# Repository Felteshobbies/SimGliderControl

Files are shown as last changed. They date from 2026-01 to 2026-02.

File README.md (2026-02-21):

# SimGliderControl
**Realistic Precision Controller for Glider Flight Simulators**

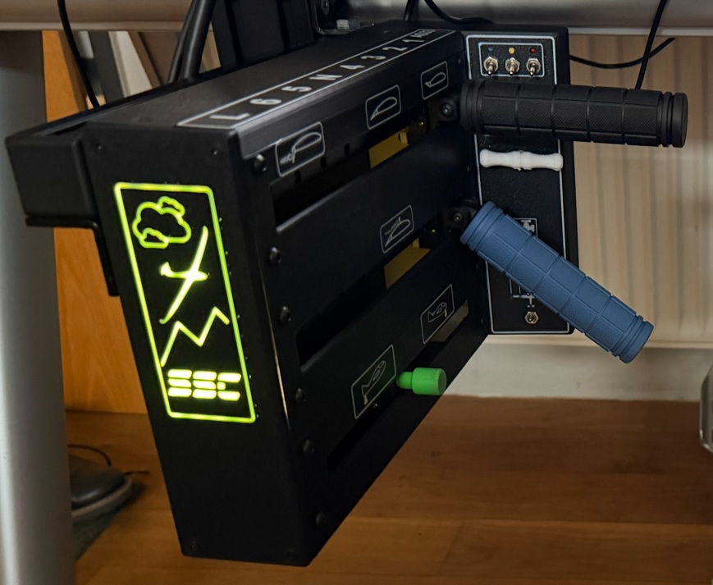
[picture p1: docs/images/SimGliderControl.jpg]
SimGliderControl


## Features
- **Flaps Control** - Smooth, precise flap adjustment
- **Spoiler Control** - Accurate spoiler/airbrake positioning  
- **Trim Control** - Fine trim adjustment with rotary knob
- **Optional Controls** - Tow release, water ballast, wheel brake, electrical systems

## Technical Specifications
- **Arduino UNO** with Mobiflight software integration (or any other controller who support analog in)
- **Ball-bearing linear guides** for smooth, realistic movement
- **Wear-free Hall effect sensors** for precise, long-lasting position detection
- **Modular design** - customize to your cockpit needs

## ⚠️ Disclaimer

This project is provided as-is for educational and hobbyist purposes. While every effort has been made to ensure accuracy, the documentation, designs, and instructions may contain errors or omissions.

**Important Notice:**
- Building and using this controller is **at your own risk**
- The author(s) assume **no liability** for any damages, injuries, or losses resulting from construction or use
- Verify all measurements, specifications, and safety considerations before proceeding
- Electronic components should be handled with appropriate safety precautions
- If you're unsure about any step, seek advice from experienced makers or professionals

By using these plans and instructions, you acknowledge and accept these terms.

## Building Your SimGliderControl

### 3D Printing Instructions
Follow these step-by-step printing guides to create all necessary components:

1. **[Step 1: Base Components](Step1/print-instructions-step1.md)** - Foundation parts including guide shafts, linear guides, and mounting brackets
2. **[Step 2: Carriage Components](Step2/print-instructions-step2.md)** - Moving parts including guides, handle mounts, and detent holders
3. **[Step 3: Enclosure and Panel](Step3/print-instructions-step3.md)** - Housing and control panel options
4. **[Step 4: Control Panel](Step4/print-instructions-step4.md)** - Main cockpit interface panels with optional decals and LED lighting
5. **[Step 5: Handles and Controls](Step5/print-instructions-step5.md)** - Ergonomic handles, trim knob, and release mechanisms

### What You'll Need
- 3D Printer (min. 250×200×200mm build volume recommended)
- PLA and PETG filament
- 1x Arduino UNO or another controller of your choice with analog in
- 3x Hall effect sensors AS5600 Encoder (23mm x 23mm) with magnet (4mm x 2mm)
- 3x MGN12 250mm linear rail with MGN12B carriage
  **Important:** Design optimized for MGN12B (short carriage) for maximum control travel
  - MGN12C compatible: mounting holes identical, but reduces available throw by ~8mm per axis
- 15x bearings 8x3x3mm
- Standard hardware (3mm and 4mm screws and nuts)
- Basic soldering equipment

## Assembly

1. **[Step 1: Base Components](docs/ASSEMBLING-STEP1.md)**
2. **[Step 2: Carriage Assembly](docs/ASSEMBLING-STEP2.md)**
3. **[Step 3: Wiring and Calibration](docs/ASSEMBLING-STEP3.md)**
4. **[Step 4: Case](docs/ASSEMBLING-STEP4.md)**
5. **[Step 5: Handles and Mounting](docs/ASSEMBLING-STEP5.md)**

## Software Setup
*Mobiflight configuration guide coming soon*

## Community
- [Sim Soaring Club Discord](https://discord.com/servers/sim-soaring-club-876123356385149009)
- [Sim Soaring Club](https://simsoaring.club/)
- [B21 Task Planner](https://xp-soaring.github.io/tasks/b21_task_planner/index.html)  
- [WeSimGlide](https://wesimglide.org/)
- [SSC-Tracker ](https://ssc-tracker.org/)

## License
Attribution-NonCommercial-ShareAlike 4.0 International

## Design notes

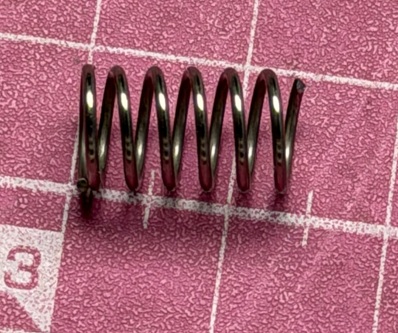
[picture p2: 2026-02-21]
docs/images/s2-6.jpg

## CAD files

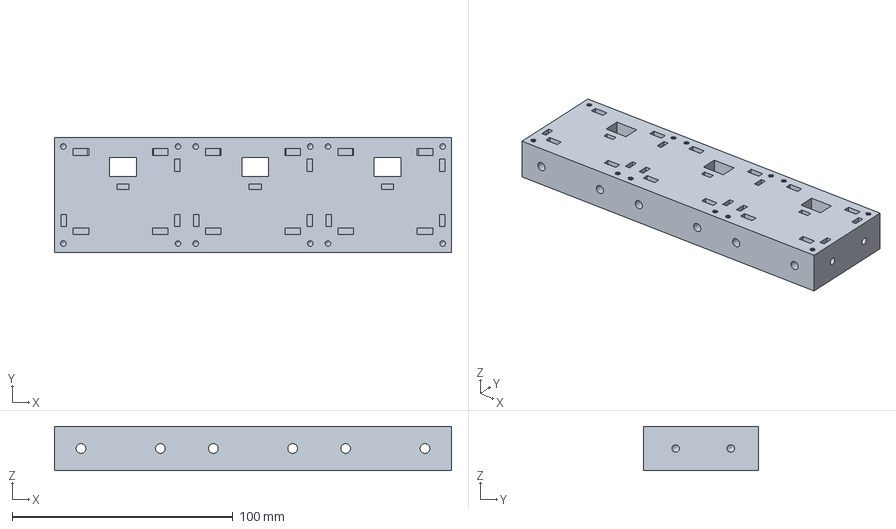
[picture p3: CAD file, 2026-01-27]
Step1/GliderCtrBase_v1-Mount2Assembly.3mf
180.0 x 52.0 x 20.0 mm

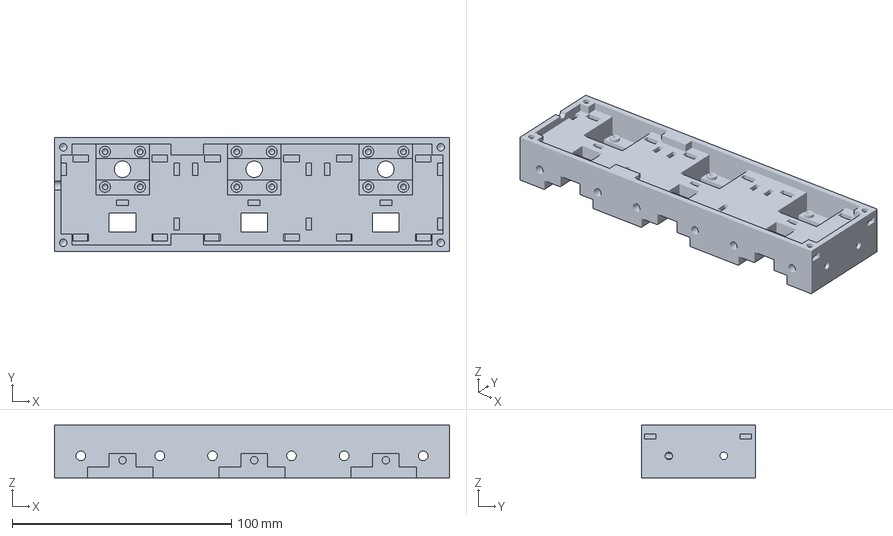
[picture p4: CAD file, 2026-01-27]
Step1/GliderCtrBase_v1-Mount1Assembly.3mf
180.0 x 52.0 x 24.0 mm

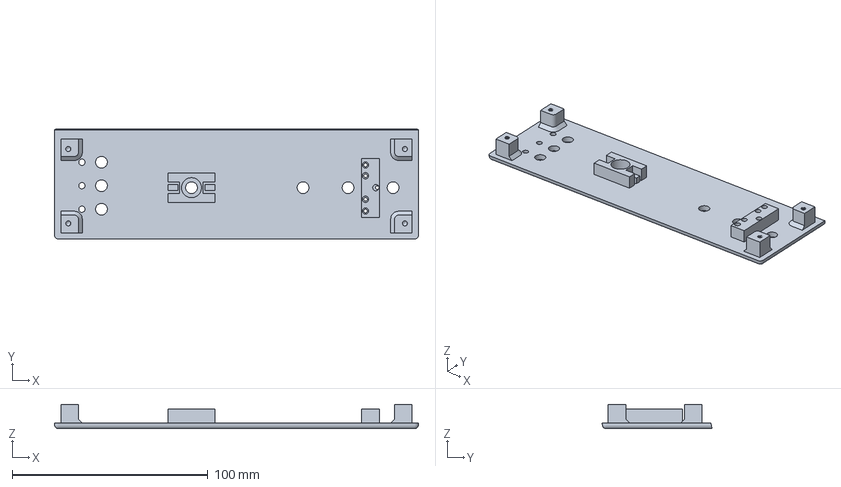
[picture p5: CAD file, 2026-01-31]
Step3/GliderCtrEnclosureAux_v1-PanelFull.3mf
186.0 x 56.2 x 12.5 mm

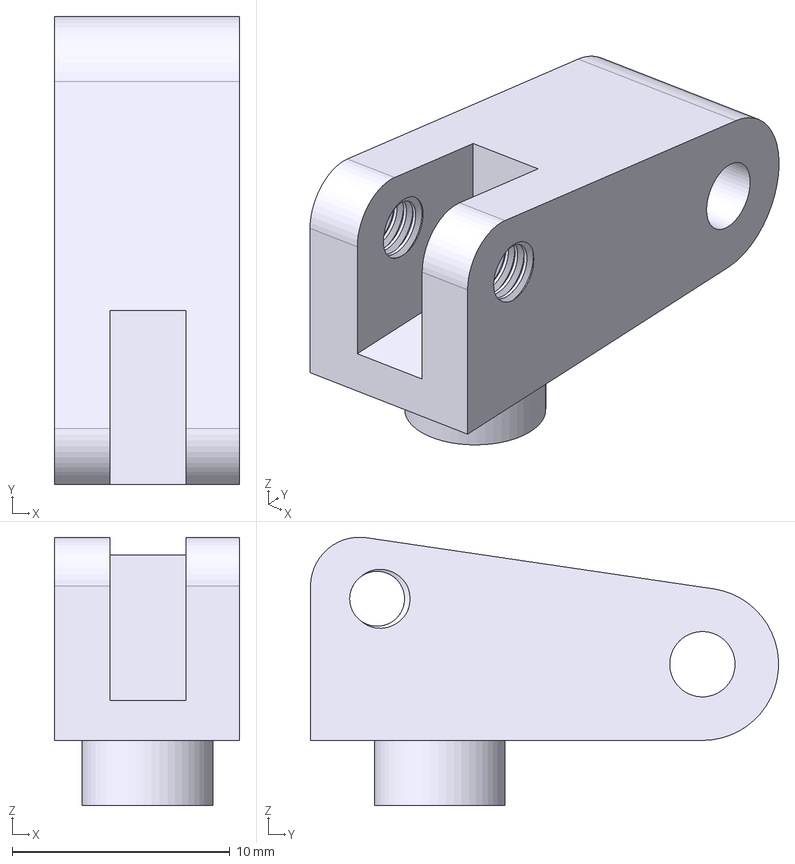
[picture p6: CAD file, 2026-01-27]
Step2/GliderCtrCarriage_v1-DetendHolder.step
8.50 x 21.5 x 12.3 mm

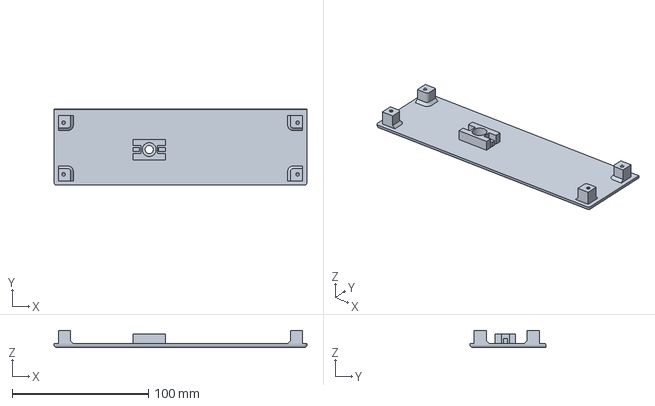
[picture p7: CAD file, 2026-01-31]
Step3/GliderCtrEnclosureAux_v1-PanelSimple.3mf
186.0 x 56.2 x 12.5 mm

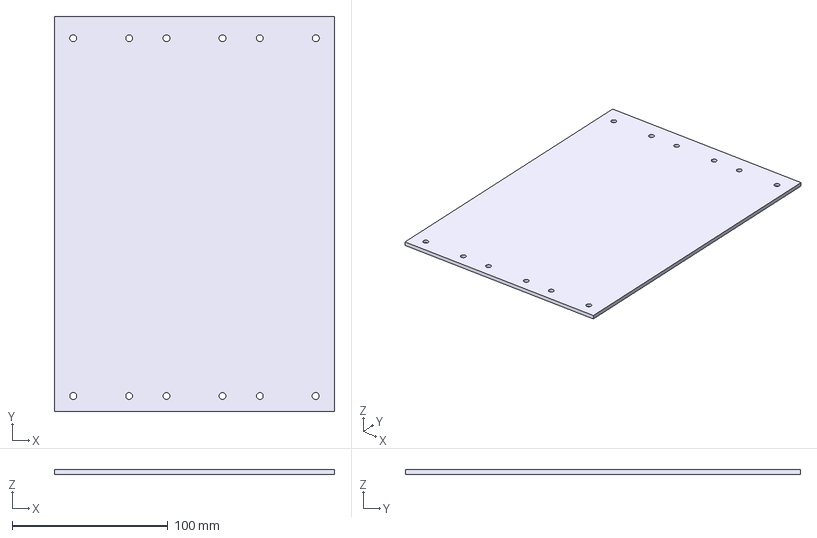
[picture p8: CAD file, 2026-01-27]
Step4/GliderCtrPanel_v1-Back.step
180.0 x 254.0 x 3.00 mm

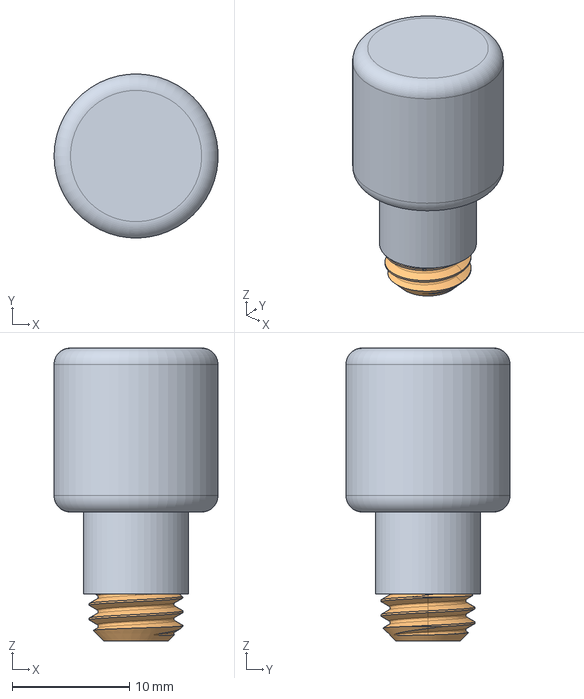
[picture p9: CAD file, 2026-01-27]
Step5/GliderCtrlHandles_v1-TrimKnob.step
14.0 x 14.0 x 25.0 mm
Knob
M8x5-ThreadedRod

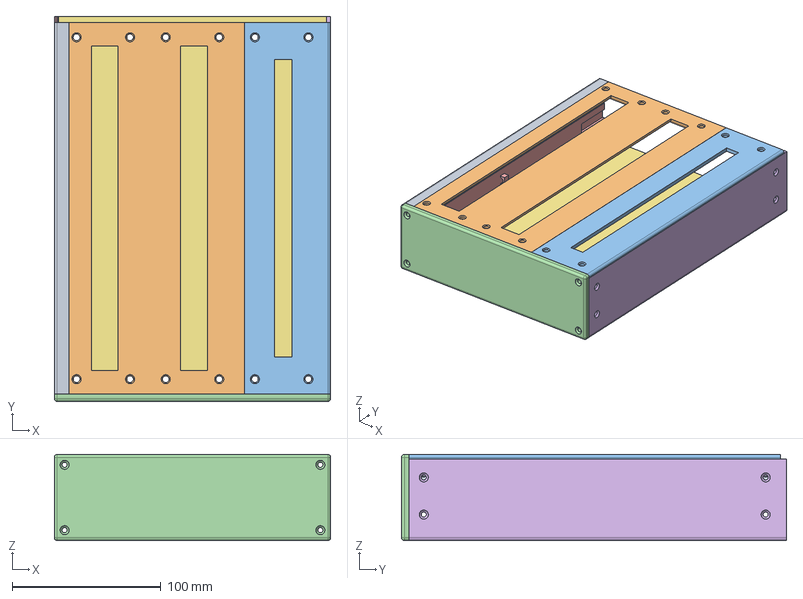
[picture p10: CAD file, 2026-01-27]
CAD/GliderCtrPanel_v1.FCStd
186.0 x 259.0 x 58.0 mm
ScaleAS33
FlapsSpoiler
Trim
front
Top
Bottom
Back

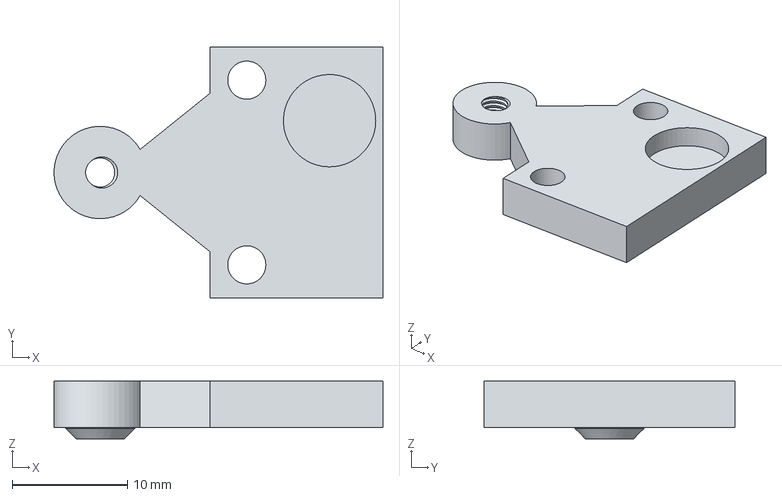
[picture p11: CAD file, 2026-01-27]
Step2/GliderCtrCarriage_v1-FixedGuide.step
28.5 x 21.7 x 5.00 mm

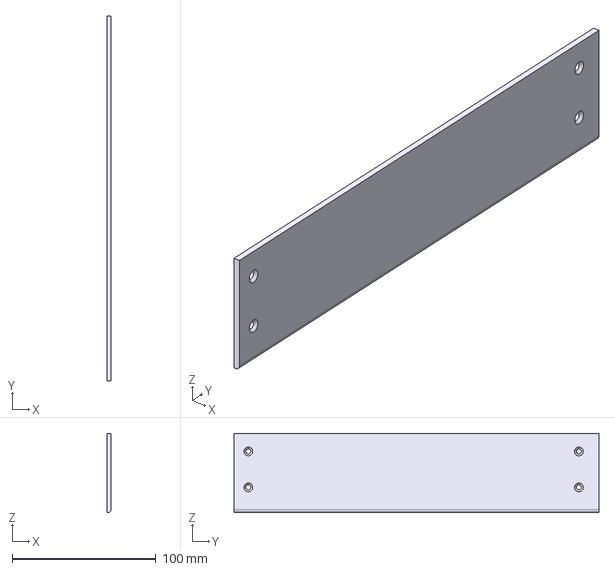
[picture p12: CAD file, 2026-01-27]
Step4/GliderCtrPanel_v1-Bottom.step
3.00 x 254.0 x 55.0 mm

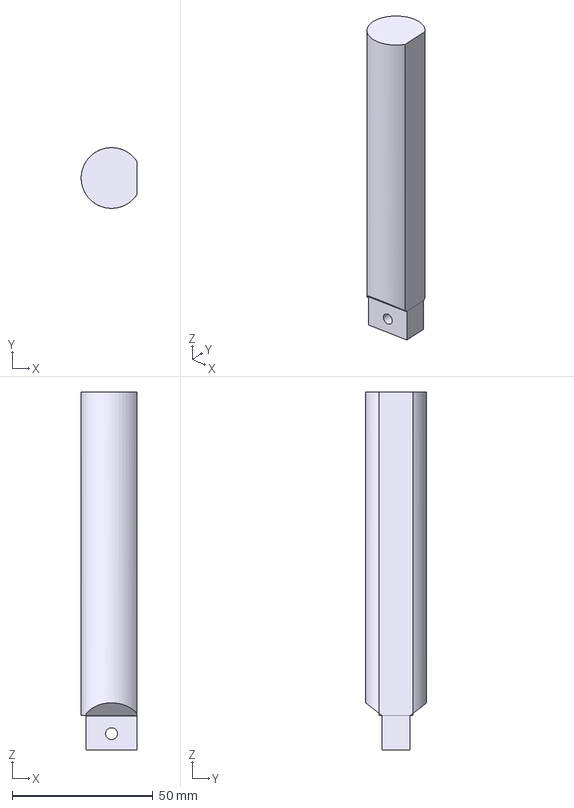
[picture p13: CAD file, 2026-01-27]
Step5/GliderCtrlHandles_v1-TrimFlap90.step
19.8 x 21.6 x 127.3 mm

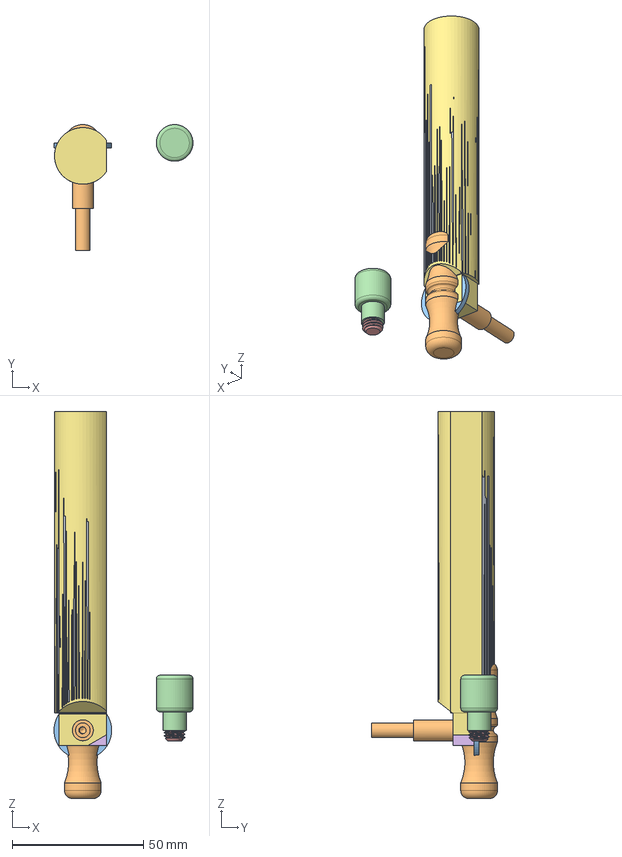
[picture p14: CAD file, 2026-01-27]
CAD/GliderCtrlHandles_v1.FCStd
53.0 x 48.0 x 147.5 mm
TrimFlap
WinchRelease
WinchReleaseMount
Knob
M8x5-ThreadedRod
TrimFlap90
TrimFlap60

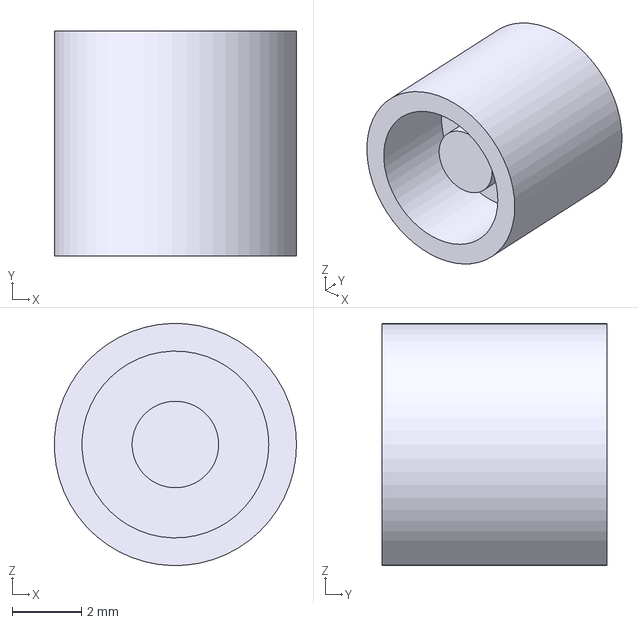
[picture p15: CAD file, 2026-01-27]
Step1/GliderCtrBase_v1-Magnetholder.step
6.99 x 6.50 x 7.00 mm

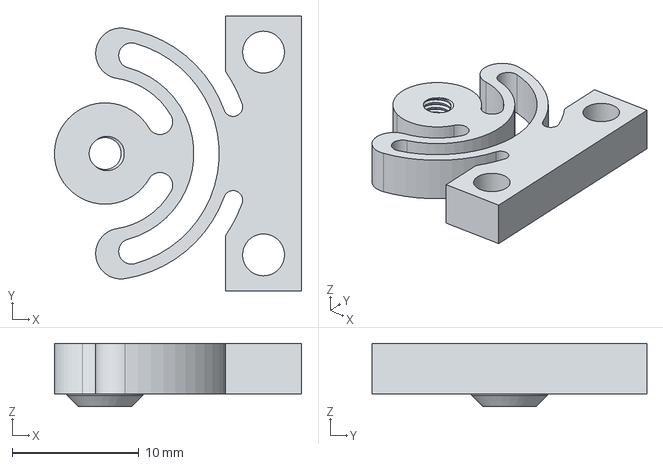
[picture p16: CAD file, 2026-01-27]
Step2/GliderCtrCarriage_v1-FlexGuide.step
19.5 x 21.7 x 5.00 mm

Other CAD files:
CAD/GliderCtrAssembly_v1.FCStd
Step3/GliderCtrEnclosureAux_v1-Enclosure.3mf
Step4/GliderCtrPanel_v1-FlapsSpoiler.step
Step5/GliderCtrlHandles_v1-WinchRelease.step
Step1/GliderCtrBase_v1-GuideShaft.3mf
Step1/GliderCtrBase_v1-GuideShaft.step
Step1/GliderCtrBase_v1-LinearGuide.3mf
Step1/GliderCtrBase_v1-LinearGuide.step
Step1/GliderCtrBase_v1-LinearGuide.stl
Step1/GliderCtrBase_v1-Magnetholder.3mf
Step1/GliderCtrBase_v1-Magnetholder.stl
Step2/GliderCtrCarriage_v1-DetendHolder.3mf
Step2/GliderCtrCarriage_v1-DetendHolder.stl
Step2/GliderCtrCarriage_v1-FixedGuide.3mf
Step2/GliderCtrCarriage_v1-FixedGuide.stl
Step2/GliderCtrCarriage_v1-FlexGuide.3mf
Step2/GliderCtrCarriage_v1-FlexGuide.stl
Step2/GliderCtrCarriage_v1-HandleMount.3mf
Step2/GliderCtrCarriage_v1-KnobMount.3mf
Step3/GliderCtrEnclosureAux_v1-PanelSimple.stl
Step4/GliderCtrPanel_v1-Back.3mf
Step4/GliderCtrPanel_v1-Back.stl
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

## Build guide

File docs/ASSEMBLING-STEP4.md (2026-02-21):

**Next Step:** Once wiring and calibration are complete and verified, proceed to [Step 5: Handles and Mounting](ASSEMBLY_STEP5.md)

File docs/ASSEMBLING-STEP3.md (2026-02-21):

# SimGliderControl - Assembly Instructions

## Step 3: Wiring and Calibration

### Mounting and Calibrating Hall Effect Sensors

### Required Parts
- 3× Hall effect sensors AS5600 Encoder (23mm × 23mm) with magnet (4mm × 2mm)
- 1× Arduino UNO or compatible
- 10× M3 button head screws 5mm length
- Wire for connections (recommend different colors for VCC, GND, and signal)
- 12× M4 nuts (for enclosure mounting)
- 4× M3 nuts (for enclosure attachment)
- 4× M3 screws 15mm length

### Software Required
- **Mobiflight Software** - Download and install from https://www.mobiflight.com/en/download.html
- **Getting Started Guide** - https://docs.mobiflight.com/getting-started/ (recommended for beginners)

---

### 3.1 Hall Sensor Operating Mode

The Hall sensors can operate in two modes: digital output or analog output. For Arduino with Mobiflight firmware, we use the **analog variant**.

**Technical specifications:**
- The sensor provides absolute analog values over the full rotation angle 0-360°
- Connected to pins A0-A2 on Arduino with 10-bit AD converter
- With ~120° rotation angle, this results in approximately 210-220 steps resolution
- Over the ~180mm control travel, resolution is less than 0.9mm

**⚠️ CRITICAL - Power Supply:**
The sensor is powered from the Arduino's **GND and 3.3V pins** (NOT 5V!)

This reduces the ~1024 possible values at the analog port to ~675. With 120° rotation angle, this is further reduced by 1/3 ≈ 220 steps.

---

### 3.2 Preparing Hall Effect Sensors

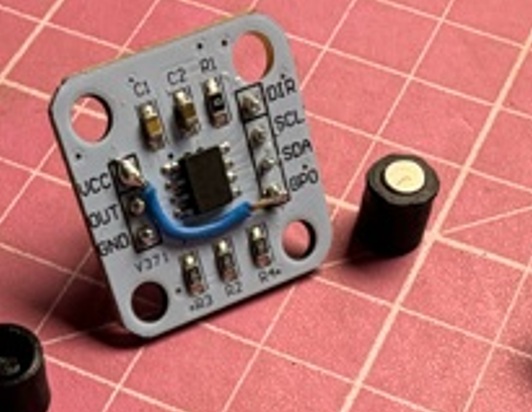
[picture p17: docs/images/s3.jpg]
Step 3 Sensor Preparation


**For analog operation:**
The GPO and VCC pins must be bridged, either as shown in the image or later via the pin headers.

**Soldering:**
Both pin headers must be soldered on the **back side** of the sensor board.

**Magnet installation:**
1. Press the magnet into the magnet holder - it should not fall out
2. If loose, add a drop of glue
3. **⚠️ Do not lose the magnet!** They have a special orientation that cannot be replaced with standard magnets

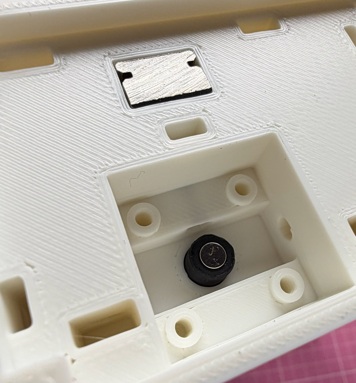
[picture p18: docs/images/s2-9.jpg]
Step 3 Magnet Holder


---

### 3.3 Mount Magnet Holders to Shafts

Press the magnet holders firmly onto the Allen screw head of each shaft. They should not fall off by themselves and must rotate freely with the shaft.

**Test fit each Hall sensor:**
- Sensors must not wobble
- Must sit flat on all 4 screw posts
- Magnet must not be pinched
- Gap should not be too large (ideally only 1-2 sheets of paper between chip and magnet)

Correct function will be verified during calibration.

---

### 3.4 Arduino Installation and Initial Wiring

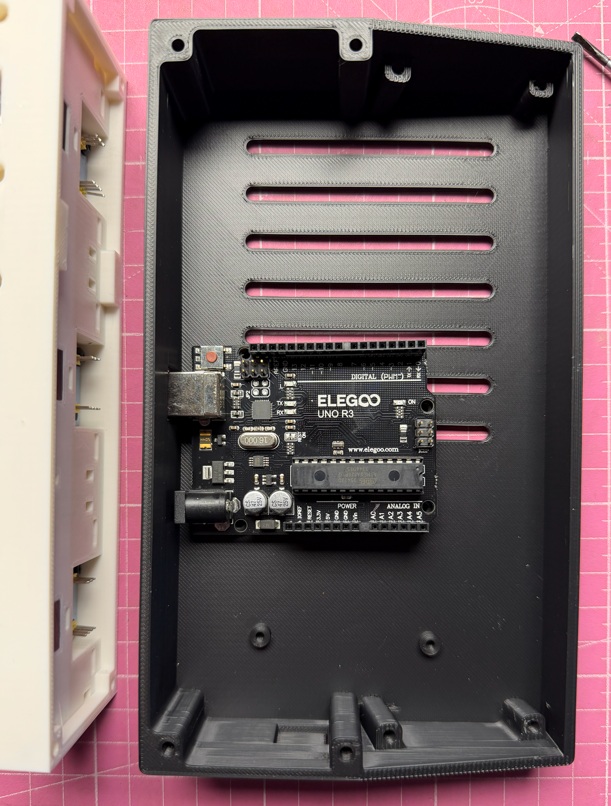
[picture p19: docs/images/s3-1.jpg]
Step 3 Arduino Mounting


1. Mount the Arduino to one of the two mounting points in the enclosure using M3 screws
2. **Initial wiring for first sensor (A0):**
   - VCC → Arduino 3.3V pin
   - GND → Arduino GND pin  
   - OUT → Arduino A0 pin

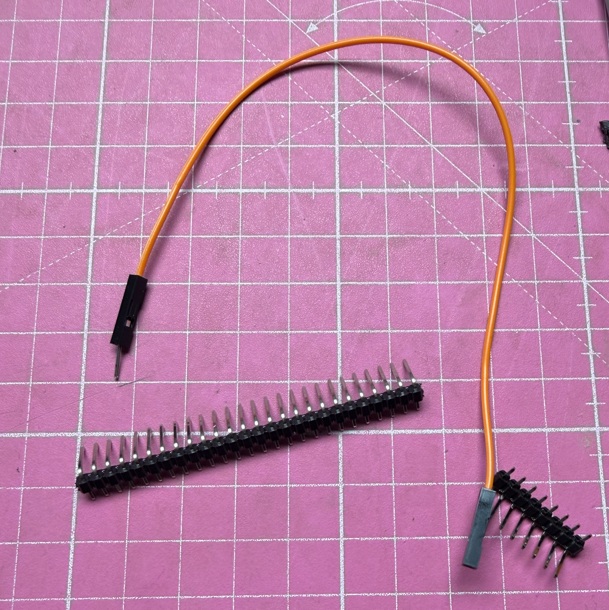
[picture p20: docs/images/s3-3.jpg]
Step 3 Wiring Detail 1

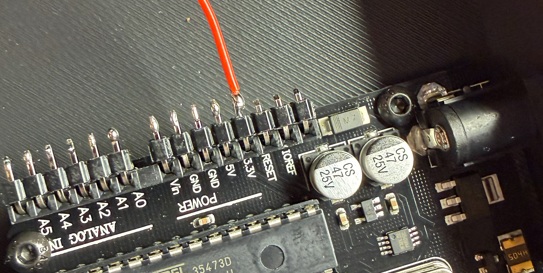
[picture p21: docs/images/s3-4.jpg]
Step 3 Wiring Detail 2


---

### 3.5 Mobiflight Firmware Setup

**Connect Arduino to PC and configure:**

1. **Start Mobiflight** and click "Mobiflight Modules"
2. The Arduino should appear in the module list as "Compatible" or "Arduino UNO"
3. Click **"Upload/Update Firmware"** at the bottom - the Arduino is then ready as a module
4. Right-click on the module and **add 3 Analog Ports** (A0, A1, A2)
5. Set **Sensitivity to High** (maximum resolution)
6. Use names: **FLAPS**, **SPOILERS**, **TRIM**
7. For minimal setup, you can also add any digital "Button" input
8. Click **"Upload config"**
9. **"Save"** module config to a file (*.mfmc)

**Configuration files:**
A Mobiflight setup consists of 2 files:
- Module Config (*.mfmc) - defines the hardware pins
- Mapping (*.mcc) - maps module ports to simulator variables

**Template files included in repository:**
- `GliderCtr.mcc` - Mapping configuration
- `MobiFlightUnoGliderCtr.mfmc` - Module configuration with MSFS SimVars

The included Mobiflight config is mapped to a different hardware ID. On first connection, you can change this via a dialog. Then save both configs.
- Every change to the module requires a new upload and save (mfmc)
- Every change to the mapping requires saving the mcc file

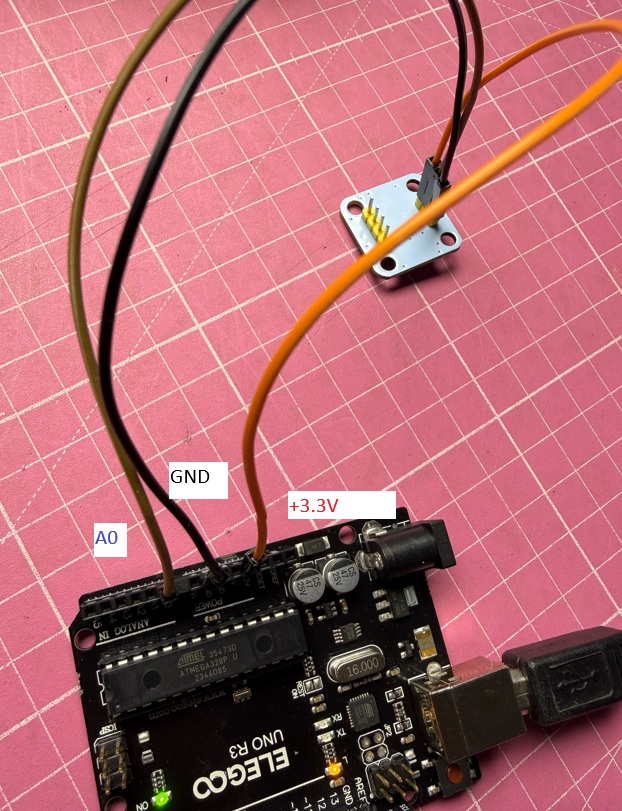
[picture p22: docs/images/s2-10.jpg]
Step 3 Mobiflight Setup 1

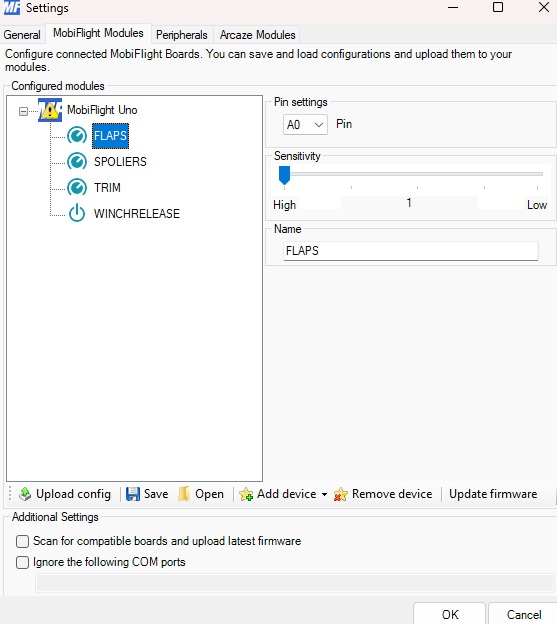
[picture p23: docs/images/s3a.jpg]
Step 3 Mobiflight Setup 2


---

### 3.6 Sensor Orientation and Calibration

For correct sensor orientation, we need a configured Arduino module and Mobiflight.

**Initial sensor test:**
1. Connect the first Hall sensor and loosely insert it into a slot (don't screw down yet)
2. In Mobiflight: **Extra > Settings** - enable **Logging and Debug**
3. In the log, you should see values from the connected input that change when you move the carriage

**⚠️ If no values appear:** Check all wiring and settings

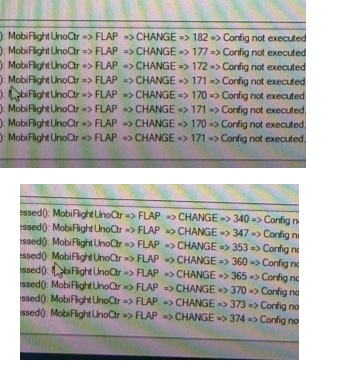
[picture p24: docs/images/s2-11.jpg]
Step 3 Calibration Values


**Example - Correct values:**
Range: 170 to 374 = 204 steps

**Critical requirement:**
Ensure that the values **do not roll over through 0** over the entire control travel.
- ❌ **Wrong:** Value1 = 600 and Value2 = 150 (rolls through zero)
- ✅ **Correct:** Minimum value must be below 400, maximum value approximately 200 steps higher

The value must later be converted via a formula to the required MSFS range of -16383 to +16383. **If the value rolls through 0, the formula will not work.**

---

### 3.7 Setting Correct Sensor Orientation

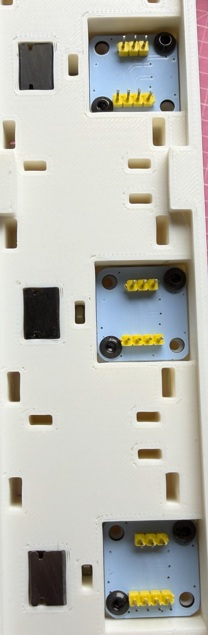
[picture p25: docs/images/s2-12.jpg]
Step 3 Sensor Orientation


1. **Rotate the sensor 90° and test again** until values increment correctly (no rollover through zero)
2. Once correct orientation is found, **fix the sensor with 2 short M3 screws**
3. **Repeat this process for all three sensors**

**Note:** In this example, all sensors happened to have identical orientation by chance. Yours may differ.

---

### 3.8 Final Wiring and Formula Configuration

Connect all sensors to the Arduino:
- Sensor 1 (FLAPS) → A0
- Sensor 2 (SPOILERS) → A1  
- Sensor 3 (TRIM) → A2

**⚠️ Do not screw on the enclosure yet!**

**Start Mobiflight again.** Now the correct values for each sensor must be entered into the formula in the Mobiflight mapping.

---

### 3.9 Calibration Formula Setup

**For each sensor:**
1. Move the carriage back and forth
2. Note the **minimum** and **maximum** values
3. Calculate the **number of steps** (max - min)
4. Enter the min value and number of steps correctly into the formula

**Formula notation:**
Mobiflight uses Polish notation (reverse notation).

---

### 3.10 Example Formulas

**Example for FLAPS:**
- Range: 170 to 374 = 204 steps
- Formula: `@ 170 - 204 / 32766 * 16383 - (>K:AXIS_FLAPS_SET)`
- Explanation: @ - 170 / 204 * 32766 - 16383

**Example for SPOILERS:**
- Range: 67 to 290 = 223 steps
- Formula: `@ 67 - 223 / 16383 * (>K:AXIS_SPOILER_SET)`

**Example for TRIM:**
- Range: 211 to 432 = 221 steps
- Formula: `@ 211 - 221 / 32766 * 16383 - -16383 max 16383 min (>K:ELEVATOR_TRIM_SET)`

**Where:**
- `@` = the analog value at the input
- First number = your minimum value
- Second number = your step count (max - min)
- Rest = MSFS command

**This calibration should only be necessary once.**

---

### 3.11 Verification Before Final Assembly

Before screwing on the enclosure, verify the function multiple times. The Hall sensors are so accurate that values at the endpoints should vary by a maximum of 2-3 steps.

**If variation is larger:**
- Check magnet holder alignment
- Verify distance to Hall sensor
- Ideally, only 1-2 sheets of paper should fit between chip and magnet

---

### 3.12 Enclosure Assembly

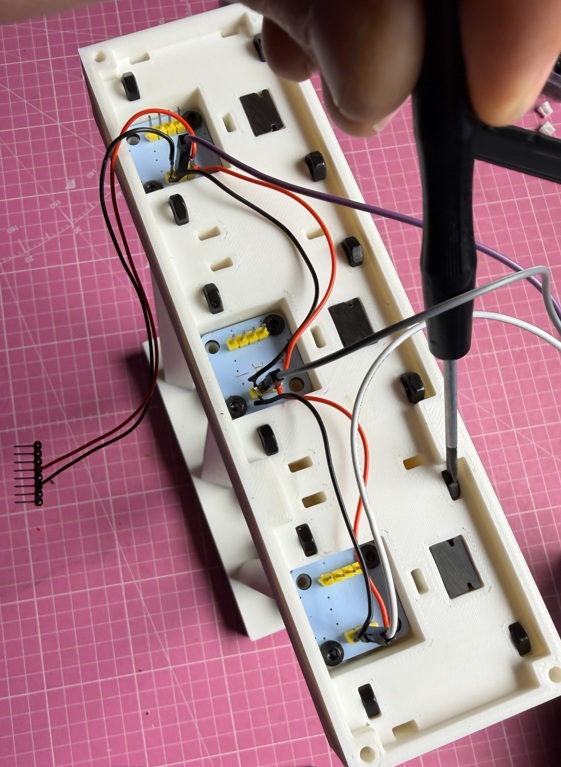
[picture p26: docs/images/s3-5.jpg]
Step 3 Enclosure Nuts 1


**Insert nuts:**
1. Insert 12× M4 nuts into the holders on both sides

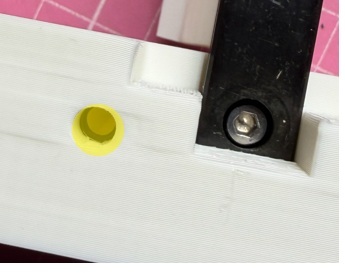
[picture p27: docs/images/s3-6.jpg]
Step 3 Enclosure Nuts 2


2. Push them in so they sit centered in the screw holes
3. Insert 4× M3 nuts for enclosure attachment into the mount

**Final assembly:**
1. Screw the enclosure on with 4× M3 15mm screws
2. **Do not pinch any cables!**
3. Depending on Arduino installation, ensure correct wiring at Arduino
4. If using additional switches and LEDs on the enclosure, connect these now

**Note on additional inputs:**
- Switches in Mobiflight are connected via GND to any I/O pin
- What additional functions you need depends on your desired configuration, the aircraft, and available variables
- This is a deep dive into the thousands of possible SimVars from Mobiflight to MSFS and other simulators

---

### 3.13 Quality Check Before Proceeding

Before moving to Step 4, verify:
- ☑ All sensors respond correctly in Mobiflight log
- ☑ No value rollover through zero
- ☑ Formulas correctly configured for all three axes
- ☑ Values stable within 2-3 steps at endpoints
- ☑ Full travel range works smoothly
- ☑ All wiring secure and not pinched
- ☑ Enclosure mounted properly

---

**Next Step:** Once wiring and calibration are complete and verified, proceed to [Step 4: Front Plates Assembly](ASSEMBLY_STEP4.md)

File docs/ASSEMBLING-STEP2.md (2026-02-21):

# SimGliderControl - Assembly Instructions

## Step 2: Carriage Assembly

### Required Parts
From printing:
- 2× GliderCtrCarriage_v1-HandleMount (for upper two rails)
- 1× GliderCtrCarriage_v1-KnobMount (for bottom trim rail)
- 3× GliderCtrCarriage_v1-FlexGuide
- 3× GliderCtrCarriage_v1-FixedGuide
- 1-3× GliderCtrCarriage_v1-DetendHolder (optional, for detent mechanism)

Additional hardware:
- 7-9× Ball bearings 8×3×3mm
- 1-3× Compression springs (8mm OD, 6mm ID, ~15mm length)
- 4× M3 countersunk screws (per carriage = 12 total)
- 9× M3 button head screws 10mm length
- 9× M3 button head screws 12mm length
- M3 button head screws 5-6mm length (for bearing mounting)

### Tools Needed
- 2.5mm Allen key
- Small screwdriver

---

### 2.1 Carriage Orientation

The carriages must be mounted on all 3 linear rails in the following orientation:

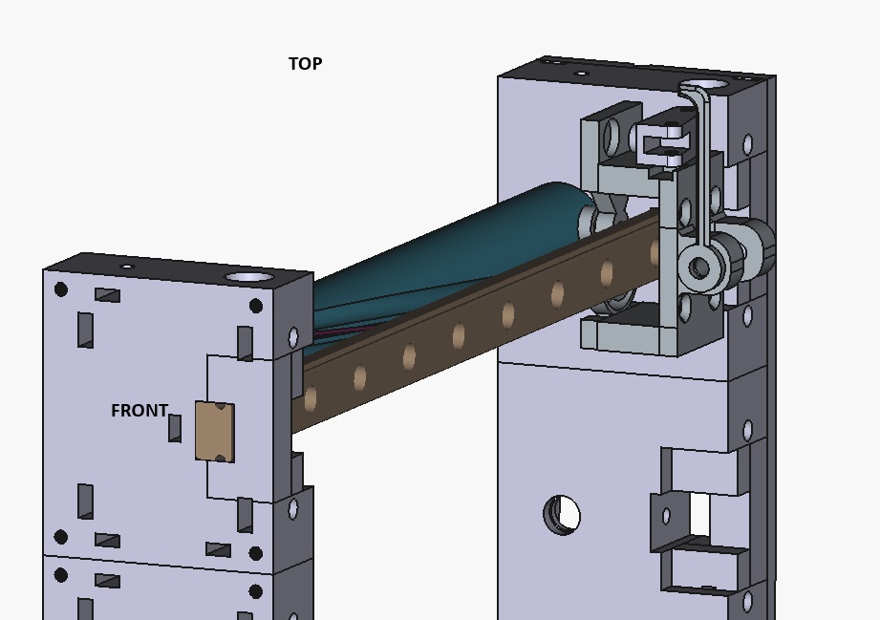
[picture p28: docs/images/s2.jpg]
Step 2 Orientation


**Important:**
- 2× HandleMount for the two upper rails (flaps and spoilers)
- 1× KnobMount for the bottom trim rail

---

### 2.2 Detent Mechanism (Optional but Recommended)

The detent mechanism with spring and ball bearing is primarily designed for the topmost flaps control. However, it can be mounted identically on the other two carriages as well. Even if detent positions are not required there, it significantly improves the haptic feel of the sliders.

**Spring Selection:**
Use 1-3 steel compression springs (8mm OD, 6mm ID, ~15mm length) depending on desired pressure. You may need to experiment with the quantity to achieve optimal feel.

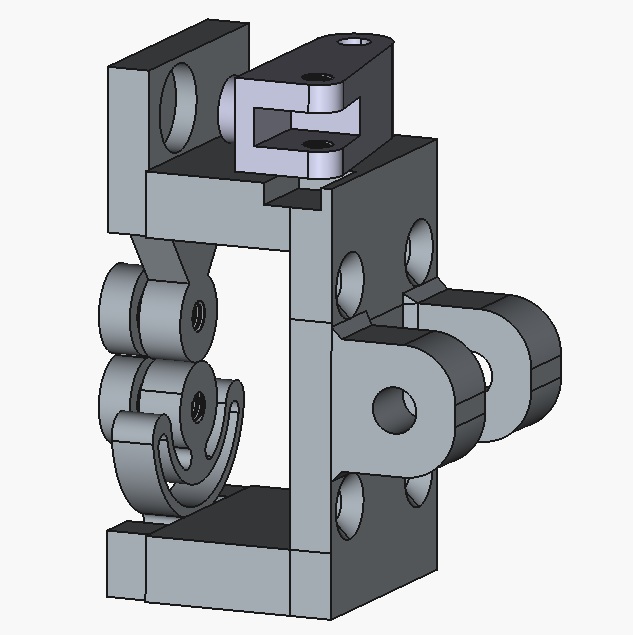
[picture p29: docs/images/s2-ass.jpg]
Step 2 Assembly Overview


---

### 2.3 Assembling the Detent Lever

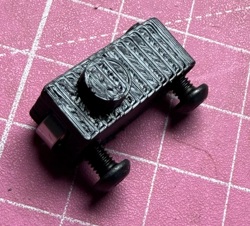
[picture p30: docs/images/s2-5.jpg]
Step 2 Detent Lever


**Required per detent assembly:**
- 3× M3 button head screws 10mm
- 3× M3 button head screws 12mm  
- 1× Ball bearing 8×3×3mm

**Assembly steps:**

1. Mount the ball bearing with the 10mm screw as shown in the image. **Do not tighten completely yet** - it will serve as a locking pin after mounting the spring.

2. Attach the lever to the mount with the 12mm screw, leaving it loose enough for the lever to move freely.

3. Insert the spring, then tighten the 10mm screw on the ball bearing just enough to hold the lever in place.

**Important:** The spring pressure should not be too strong. We will test this shortly on the carriage with the flaps detent plate.

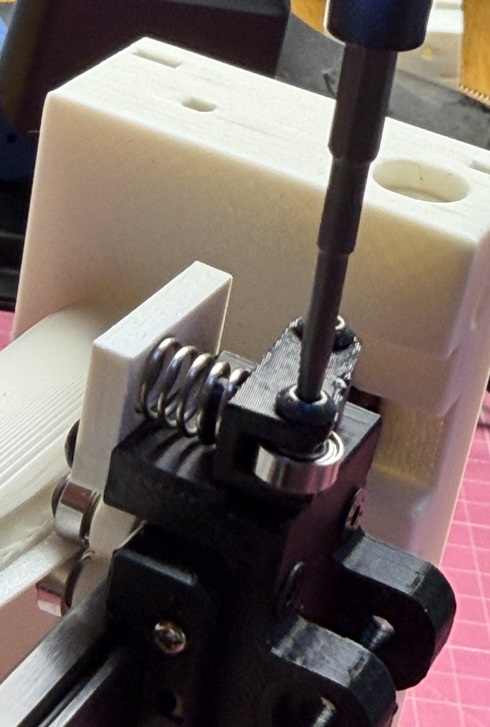
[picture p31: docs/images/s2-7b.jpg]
Step 2 Detent Detail


---

### 2.4 Mount Carriage to Linear Rail

Mount each HandleMount/KnobMount to the rail carriage using 4× M3 countersunk screws.

**Critical:** The screw heads must be flush or below the surface - there is very little clearance for the cover later.

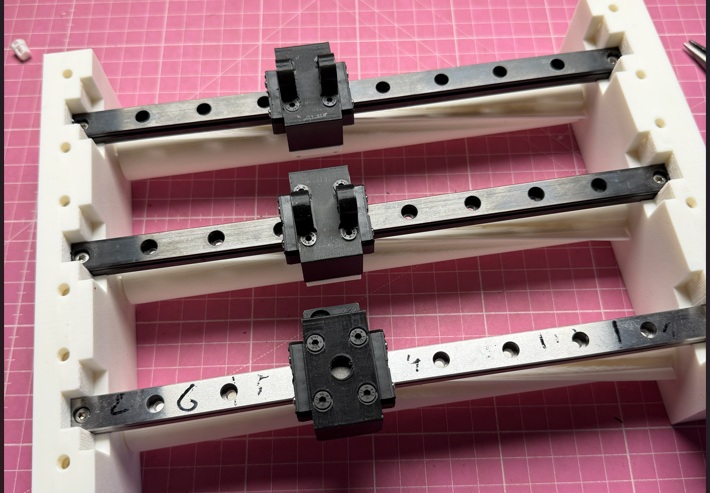
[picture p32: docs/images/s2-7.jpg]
Step 2 Mounting


---

### 2.5 Test Detent Pressure

Place the detent plate on top for testing and check the spring pressure. The plate will be held securely by magnets later, but it should not bend under the spring pressure.

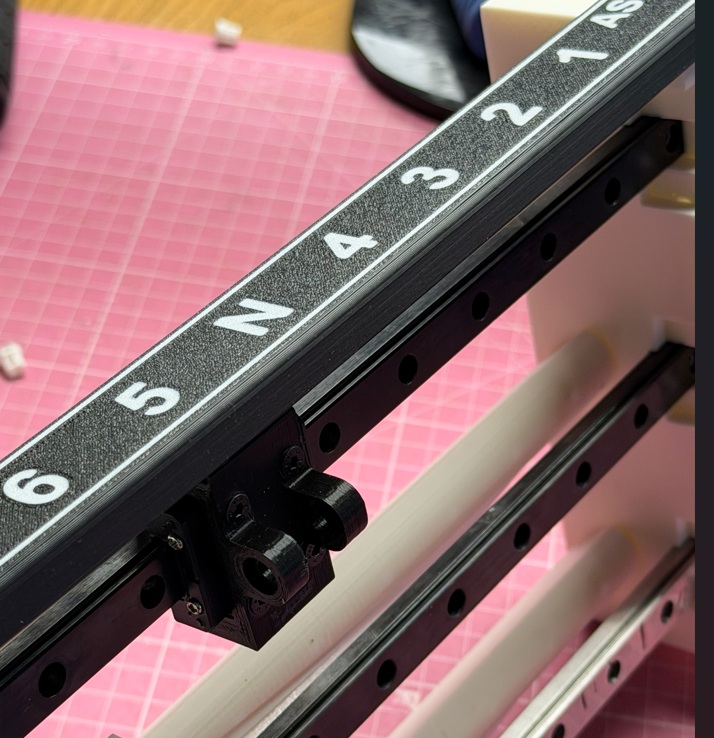
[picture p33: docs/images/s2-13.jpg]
Step 2 Detent Test


**Adjustment:** If pressure is too high or too low, adjust by:
- Adjust spring length
- Using different spring strengths

---

### 2.6 Mount Guide Bearings

Now mount the guides on all 3 carriages.

**Preparation:**
1. First, carefully attach all bearings to the raised side of the 3 FlexGuides and 3 FixedGuides using M3 button head screws (5-6mm length).

**Assembly sequence:**
1. Mount one side (bottom) to the mount first
2. Loosely attach the opposite guide with just one screw initially
3. Rotate the shaft so the guide presses against the fixed bearing
4. Then tighten the second bearing

**Critical adjustment:** There should be no play, but also not too much pressure. If necessary, loosen the screws and adjust the holders in the screw holes.

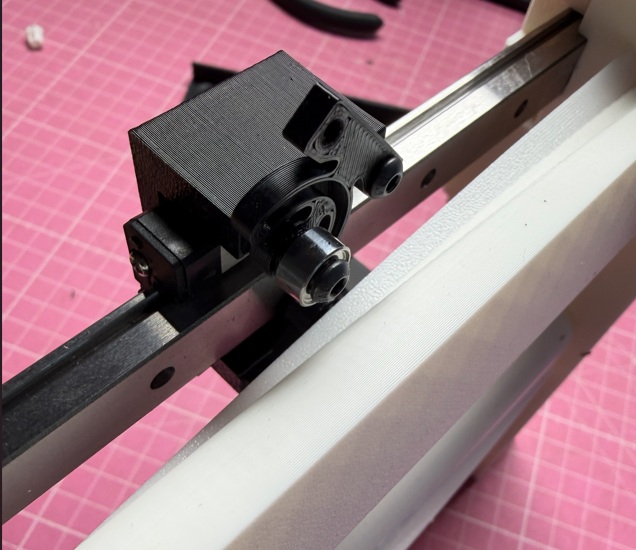
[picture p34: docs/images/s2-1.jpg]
Step 2 Guide Assembly 1

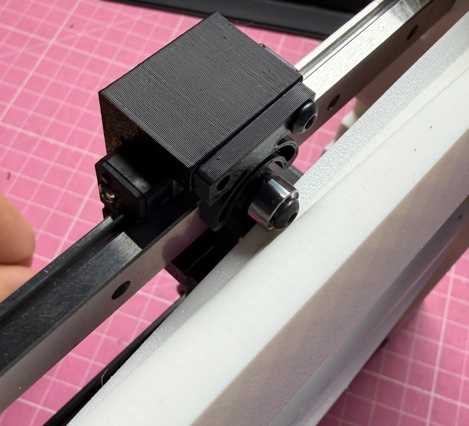
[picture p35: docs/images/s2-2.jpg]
Step 2 Guide Assembly 2


---

### 2.7 Movement Test

Move the carriage back and forth several times. It should move smoothly and securely over the entire length of the rail.

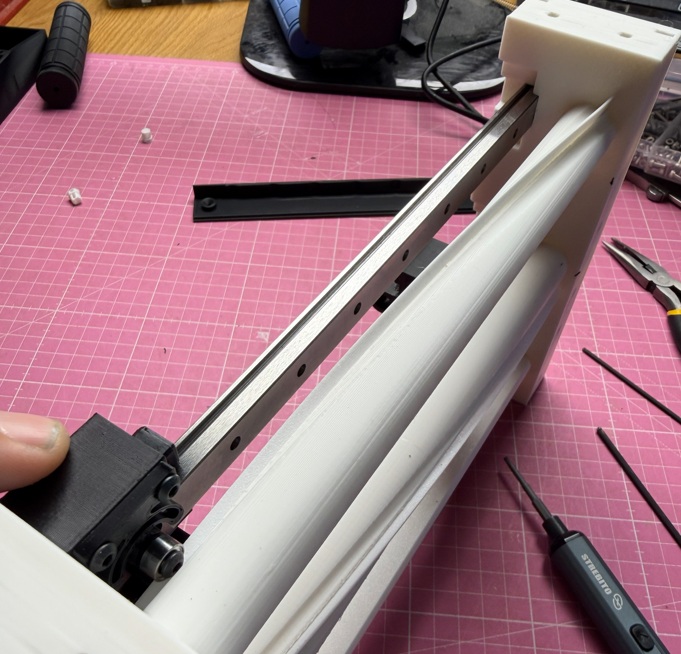
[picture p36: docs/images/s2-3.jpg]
Step 2 Movement Test


**If movement is stiff or rough:**
- Check bearing alignment
- Verify no screws are protruding
- Adjust guide pressure by loosening/repositioning
- Ensure FlexGuide has slight flexibility

---

### 2.8 Final Verification

Before proceeding, verify:
- ☑ Orientation matches the first image in this step
- ☑ KnobMount is on the bottom (trim) rail
- ☑ All carriages move smoothly over full travel
- ☑ No excessive play in guides
- ☑ Detent mechanism engages properly (if installed)

---

**Next Step:** Once the carriage assembly is complete and verified, proceed to [Step 3: Calibrating and Wiring](ASSEMBLING-STEP3.md)

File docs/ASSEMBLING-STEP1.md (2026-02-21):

# SimGliderControl - Assembly Instructions

## Step 1: Base Assembly - Mounting Control Shafts and Linear Rails

### Required Parts
From printing:
- 3× GliderCtrBase_v1-GuideShaft
- 3× GliderCtrBase_v1-LinearGuide
- 1× GliderCtrBase_v1-Mount1Assembly and  Mount2Assembly
- 3× LinearGuide and carriage (MGN12B/C rails) (Maybe cleanup from too much oil required)

Additional hardware:
- 6× Ball bearings 8×3×3mm
- 12× M3 Allen head screws, 15mm length
- 6× M3 nuts
- M3 washers (quantity varies - 2-4 per shaft depending on tolerance)

### Tools Needed
- 2.5mm Allen key
- Small flat-head screwdriver (for nut insertion)

---

### 1.1 Attach Ball Bearings to Control Shafts

Gently push the LinearGuide into the slot of the GuideShaft. A tight friction fit should hold it in place without glue. If the fit is too loose and has excessive play, ensure the guide is pushed completely to the end of the slot before applying a small amount of glue to secure it.

Screw a ball bearing (8×3×3mm) to each end of all 3 control shafts using 15mm Allen head screws.

**Important:** Depending on your print tolerances, use 1-2 washers on the shaft side. Whether you need more or fewer washers will become apparent only after fixing the linear rails in place.

**Note:** The screw head must be positioned as shown in the image. The magnet holder that will be slid on later is designed for this screw head size.

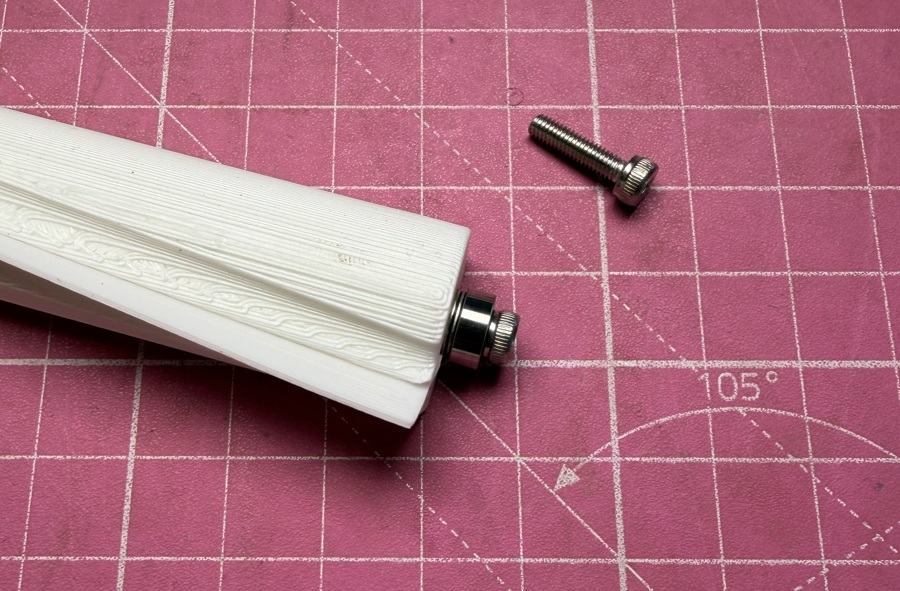
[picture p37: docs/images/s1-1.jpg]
Step 1-1


---

### 1.2 Insert Nuts into Mount Brackets

Insert 6× M3 nuts into the slots on both mount brackets and push them down until they sit centered with the screw holes.

**Tip:** Use a small screwdriver to push the nuts firmly into position.

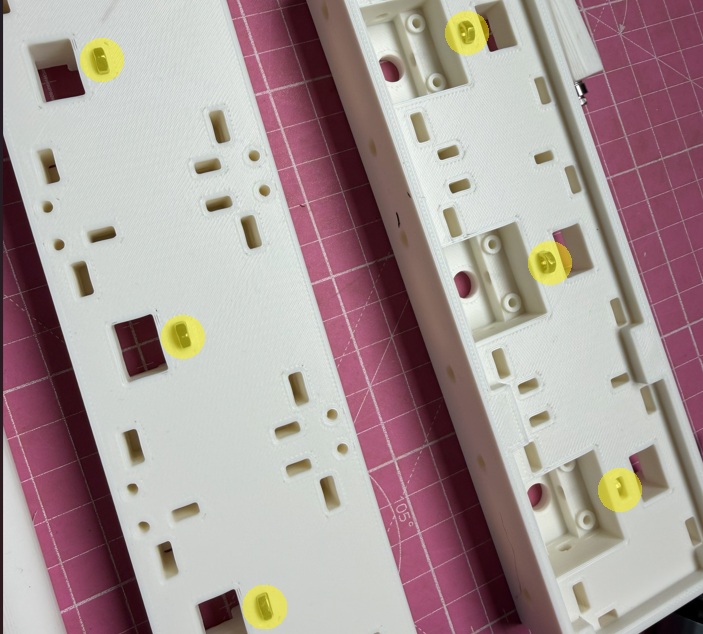
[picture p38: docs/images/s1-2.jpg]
Step 1-2

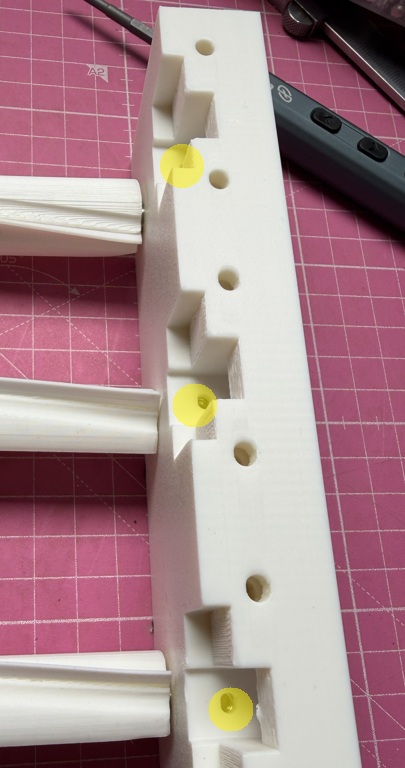
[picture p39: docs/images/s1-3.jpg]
Step 1-3


---

### 1.3 Assemble First Side

Place one mount bracket upright and press all 3 shafts with bearings into position. Then slide in the linear rails as shown in the image.

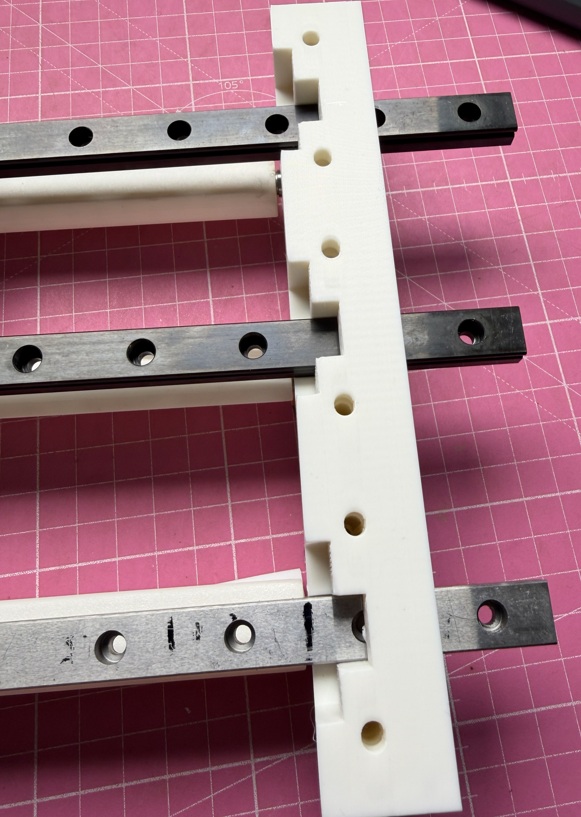
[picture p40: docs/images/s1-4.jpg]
Step 1-4


---

### 1.4 Attach Second Mount Bracket

Press the bearings on the opposite side into the second mount bracket.

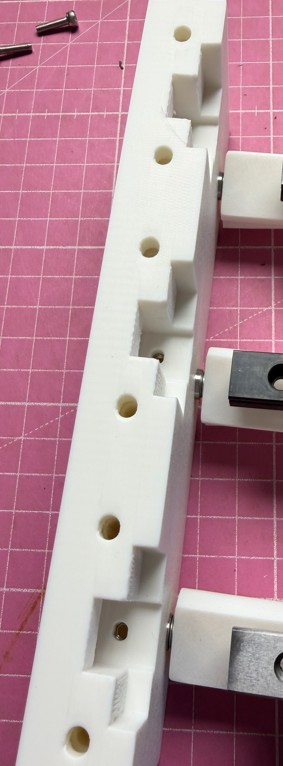
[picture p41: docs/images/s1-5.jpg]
Step 1-5


---

### 1.5 Alignment and Adjustment

Align the linear rails with the screw holes on both sides to check if the spacing is correct.

**Critical Adjustment:**
- You may need to add or remove washers on one shaft end
- The shafts should have **no play** (no wobble)
- The two mount brackets must **not push apart** from each other
- There should be slight preload, but not excessive tension

**Verification:**
Place the control panel on top to verify that both mount brackets are positioned at equal distance from each other and parallel.

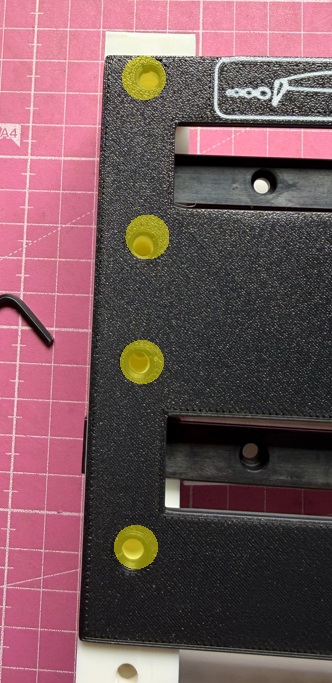
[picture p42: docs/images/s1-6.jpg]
Step 1-6

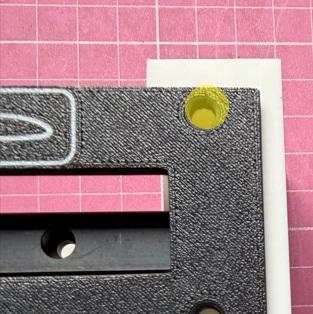
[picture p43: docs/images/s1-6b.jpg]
Step 1-6b


Fix the linear rail with 6 M3 Allen head screws, 15mm and don't forget the MGN12B/C carriage before. 

---

### 1.6 Quality Check Before Proceeding

Before moving to Step 2, verify:
- ☑ All bearings rotate smoothly
- ☑ No play in the shafts
- ☑ Mount brackets are parallel and properly spaced
- ☑ Linear rails are aligned and seated properly
- ☑ MGN12B/C carriages is moving smoothly

---

**Next Step:** Once the base assembly is complete and verified, proceed to [Step 2: Carriage Assembly](ASSEMBLING-STEP2.md)

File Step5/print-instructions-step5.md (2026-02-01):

# SimGliderControl - Print Instructions

## Step 5: 3D Printing Handles and Control Elements

###  Flap/Trim Handles (Flexible Mount)
**Material:** PETG (black)  
**Layer Height:** 0.2 mm  
**Perimeters:** 3  
**Infill Density:** 30%  
**Support:** no

**Parts to print:**
- 2× `GliderCtrlHandles_v1-TrimFlap` *(for adjustable angle mounting)*

or use `GliderCtrlHandles_v1-TrimFlap60` *(60° fixed angle)*  or  `GliderCtrlHandles_v1-TrimFlap90` *(90° fixed angle)*

### Trim Knob
**Material:** PLA (green)  
**Layer Height:** 0.2 mm  
**Perimeters:** 3  
**Infill Density:** 30%  
**Support:** Yes - support on build plate only

**Parts to print:**
- 1× `GliderCtrlHandles_v1-TrimKnob`

**Print Notes:** 
- Green color matches authentic glider trim knobs

###  Winch Release Components
**Material:** PETG (yellow)  
**Layer Height:** 0.2 mm  
**Perimeters:** 3  
**Infill Density:** 100%  
**Support:** Yes - support on build plate only

**Parts to print:**
- 1× `GliderCtrlHandles_v1-WinchRelease`
- 1× `GliderCtrlHandles_v1-WinchReleaseMount`

---

###  Position Pointer
**Material:** PETG (white or on your choice)  
**Layer Height:** 0.2 mm  
**Perimeters:** 3  
**Infill Density:** 100%  
**Support:** None

**Parts to print:**
- 1× `GliderCtrCarriage_v1-Pointer`

**Print Notes:** 
- White provides high contrast against black panel for easy position reading
- 100% infill ensures rigidity

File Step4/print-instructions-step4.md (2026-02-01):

# SimGliderControl - Print Instructions

## Step 4: 3D Printing the Control Panels

### Print Settings Overview
These are the main cosmetic panel parts that form the visible cockpit interface.
I prefer a rough print plate for a good finish

---

### Panel Components - Standard Settings
**Material:** PLA (black or color of your choice)  
**Layer Height:** 0.2 mm  
**Perimeters:** 3  
**Infill Density:** 15%  
**Support:** None

**Parts to print:**
- 1× `GliderCtrPanel_v1-Back` *(see note below if too large for your print bed)*
- 1× `GliderCtrPanel_v1-Bottom`
- 1× `GliderCtrPanel_v1-FlapsSpoiler`
- 1× `GliderCtrPanel_v1-Front`
- 1× `GliderCtrPanel_v1-ScaleAS33`
- 1× `GliderCtrPanel_v1-Top`
- 1× `GliderCtrPanel_v1-Trim`

**Print Notes:** 
- All parts should match in color for a cohesive look
- Black recommended for authentic cockpit appearance
- Quality surface finish is important as these are highly visible parts

---

### Large Part Handling

**GliderCtrPanel_v1-Back:**
If this part doesn't fit your print plate, you have two options:
1. **Cut and print in 2-3 parts** - Join parts after printing with glue or screws
2. **Print diagonally cutet parts** - Rotate 45° to maximize bed usage

---

### Optional Multi-Material Decals

For enhanced realism, you can use multi-material printing with the following decals:

**Decal Files:**
- `Decals/as33flasp.svg` - for GliderCtrPanel_v1-FlapsSpoiler
- `Decals/logo2.svg` - for GliderCtrPanel_v1-Front
- `Decals/as33scal.svg` - for GliderCtrPanel_v1-ScaleAS33
- `Decals/as33Trim.svg` - for GliderCtrPanel_v1-Trim

**Multi-Material Printing:**
- Import SVG decals into your slicer
- Use contrasting color (white on black recommended)
- Set decal depth to 0.2-0.4 mm for best visibility
- Not required but adds professional cockpit appearance

---

### LED Lighting Feature

**GliderCtrPanel_v1-Front** includes a cutout designed for LED strip backlighting:
- The cutout allows LED strips to illuminate panel markings
- Use with translucent filament or decals for best effect
- LED installation covered in assembly instructions

---

**Next Step:** Once all panel parts are printed and finished, proceed to Step 5: Handle and Knob Components.

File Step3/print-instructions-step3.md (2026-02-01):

# SimGliderControl - Print Instructions

## Step 3: 3D Printing the Enclosure and Panel

### Print Settings Overview
These cosmetic parts can be printed in your preferred color to match your cockpit setup.
I prefer to print this on a rough print plate for a good finish

---

### Enclosure Components - Standard Settings
**Material:** PLA (black or color of your choice)  
**Layer Height:** 0.2 mm  
**Perimeters:** 4  
**Infill Density:** 15%  
**Support:** None

**Parts to print:**
- 1× `GliderCtrEnclosureAux_v1-Enclosure`

**AND choose ONE panel option:**
- 1× `GliderCtrEnclosureAux_v1-PanelSimple` *(basic version, no auxiliary controls)*

**OR**
- 1× `GliderCtrEnclosureAux_v1-PanelFull` *(with cutouts for auxiliary switches and LEDs)*
*add as33panel.svg if you familiar with mulitmaterial printing*

**Print Notes:** 
- Choose a color that matches or complements your sim cockpit
- Black is recommended for a professional look
- The panel choice is NOT permanent - you can reprint and swap panels later

---

### Panel Selection Guide

**PanelSimple:**
- Clean, minimalist design
- No auxiliary controls
- Best for basic flaps/spoilers/trim/ballast operation
- easy built

**PanelFull:**
- Includes cutouts for switches and LEDs
- Allows future expansion without reprinting enclosure
- Recommended if you plan to add auxiliary controls later

---
### Before You Continue
- Check that panel fits smoothly into the enclosure
- Verify that all cutouts (if using PanelFull) are clean and free from strings
- Test the finish quality

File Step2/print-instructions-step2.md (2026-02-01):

# SimGliderControl - Print Instructions

## Step 2: 3D Printing the Carriage Components

### Carriage Parts - Standard Settings
**Material:** PETG  (black or dark color)
**Layer Height:** 0.2 mm  
**Perimeters:** 4  
**Infill Density:** 50%  
**Support:** None

**Parts to print:**
- 1× `GliderCtrCarriage_v1-DetendHolder` *(optional: 2× for spoilers and trim, If you plan to add another smoother feedback to your spoilers and trim controls)*
- 3× `GliderCtrCarriage_v1-FixedGuide`
- 3× `GliderCtrCarriage_v1-FlexGuide`
- 1× `GliderCtrCarriage_v1-KnobMount` *(for trim control)*

**Print Notes:** 
- PETG is recommended for these parts due to its flexibility and durability under repeated movement
- The FlexGuides benefit from PETG's slight flexibility for smooth operation
- All parts should be printed in the same orientation as shown in the STL,3MF files

**Support:** All (partially)
- 2× `GliderCtrCarriage_v1-HandleMount` (3mf file include the partially support setup)


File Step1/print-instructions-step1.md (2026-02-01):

# SimGliderControl - Print Instructions

## Step 1: 3D Printing the Base Components

### Print Settings Overview
All parts should be printed in the same orientation as shown in the STL,3mf files.

---

### Group 1: Guide Shafts and Magnet Holders
**Material:** PLA  
**Layer Height:** 0.2 mm  
**Perimeters:** 2  
**Infill Density:** 15%  
**Support:** None

**Parts to print:**
- 3× `GliderCtrBase_v1-GuideShaft`
- 3× `GliderCtrBase_v1-Magnetholder`

**Print Notes:** These lightweight parts don't require high strength, so minimal infill is sufficient.

---

### Group 2: Linear Guides
**Material:** PLA  
**Layer Height:** 0.2 mm  
**Perimeters:** 5  
**Infill Density:** 100%  
**Support:** None

**Parts to print:**
- 3× `GliderCtrBase_v1-LinearGuide`

**Print Notes:** These parts require high strength and dimensional accuracy for smooth slider movement. The increased perimeters and 100% infill ensure durability and smoothness.

---

### Group 3: Mount Assemblies
**Material:** PLA (PETG recommended for better durability)  
**Layer Height:** 0.2 mm  
**Perimeters:** 4  
**Infill Density:** 40%  
**Support:** Yes - support on build plate only

**Parts to print:**
- 1× `GliderCtrBase_v1-Mount1Assembly`
- 1× `GliderCtrBase_v1-Mount2Assembly`

**Print Notes:** These mounting brackets will bear mechanical loads. PETG is recommended for better layer adhesion and strength.

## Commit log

2026-01-27 Update README with FreeCad 1.02 information
    Add introductory text for FreeCad 1.02 CAD files
2026-02-01 Add print instructions for 3D printing base components
    Added detailed print instructions for 3D printing base components, including settings for different groups of parts.
2026-02-01 Add 3D printing instructions for carriage components
    Added detailed printing instructions for carriage components, including material specifications, layer height, and part list.
2026-02-01 Add print instructions for enclosure and panel options
    Added detailed print instructions for the enclosure and panel options, including print settings, component lists, and panel selection guide.
2026-02-01 Update print instructions for enclosure components
    Added note about including as33panel.svg for multi-material printing.
2026-02-01 Add printing instructions for SimGliderControl panels
    Added detailed printing instructions for the control panels, including print settings, part handling, optional decals, and LED lighting features.
2026-02-01 Update 3D printing instruction links to new paths
2026-02-01 Fix formatting of 3D printing instructions in README
2026-02-01 Fix case sensitivity in printing instruction links
    Updated links in 3D printing instructions to use lowercase file names.
2026-02-01 Revise linear rail description and add compatibility info
    Updated the description of linear rail components and added compatibility note for MGN12C.
2026-02-01 Add ASSEMBLING-STEP1.md documentation file
2026-02-01 Add image to ASSEMBLING-STEP1.md
2026-02-01 Add assembly instructions for base setup
    Added detailed assembly instructions for the base, including required parts, tools, and step-by-step guidance for mounting control shafts and linear rails.
2026-02-01 Update README with assembly step and notes
    Added initial assembly step and updated instructions.
2026-02-01 Update Arduino controller description in README
    Clarified the description of the Arduino controller requirement.
2026-02-01 Fix dimensions of ball bearings and linear guides
2026-02-01 Revise parts list and add assembly details
    Updated required parts list and assembly instructions for clarity.
2026-02-21 Add Step 2 to assembly instructions in README
2026-02-21 Fix link to Step 2 in ASSEMBLING-STEP1.md
2026-02-21 Document assembly instructions for carriage step 2
    Added detailed assembly instructions for the carriage, including parts list and step-by-step guidance on mounting and adjustments.
2026-02-21 Revise carriage assembly instructions and details
    Updated assembly instructions for the carriage, including required parts, tools, and detailed assembly steps.
2026-02-21 Revise spring adjustment guidance and checklist
    Updated adjustment instructions for spring tension and removed checklist item about screws.
2026-02-21 Fix link to Step 4 in ASSEMBLING-STEP3.md
2026-02-21 Fix link to Step 3 in ASSEMBLING-STEP2.md
2026-02-21 Revise wiring and calibration instructions for sensors
    Updated assembly instructions for wiring and calibrating Hall effect sensors, including required parts, software setup, and calibration procedures.
2026-02-21 Update assembly steps in README.md
2026-02-21 Update ASSEMBLING-STEP4 with next steps
    Added a note to proceed to Step 5 after wiring and calibration.
